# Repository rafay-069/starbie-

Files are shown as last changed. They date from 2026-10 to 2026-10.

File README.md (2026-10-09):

# Starbie: Yeti J.A.R.V.I.S. Edition

An expressive desktop companion robot and PC voice automation assistant housed inside a custom 3D-printed Yeti figurine, designed for the **Hack Club Half-Life** hardware initiative[cite: 5, 7].






---

## 3D Render & Board Preview

| 3D Carrier Board & Clearance | 2D Routed Copper Layout (0 DRC Errors) |
| :---: | :---: |
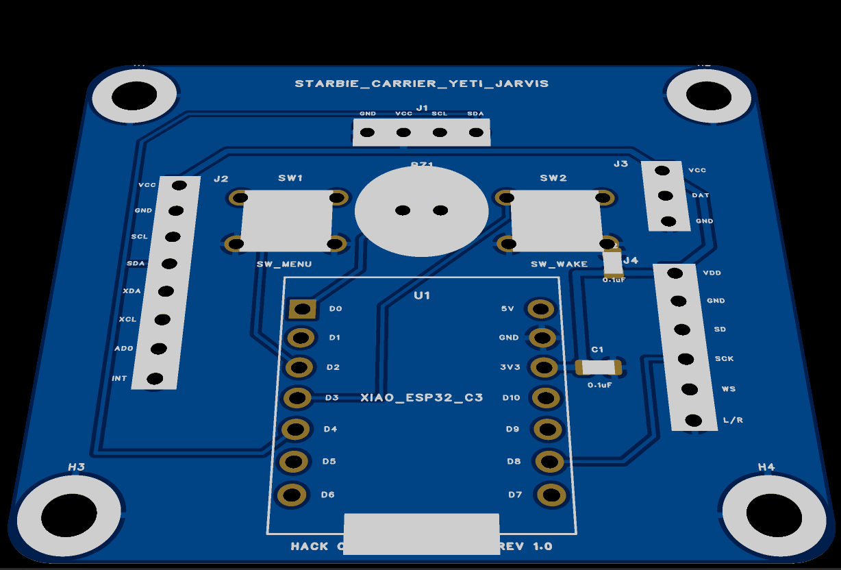
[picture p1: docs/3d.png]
Starbie PCB 3D Render
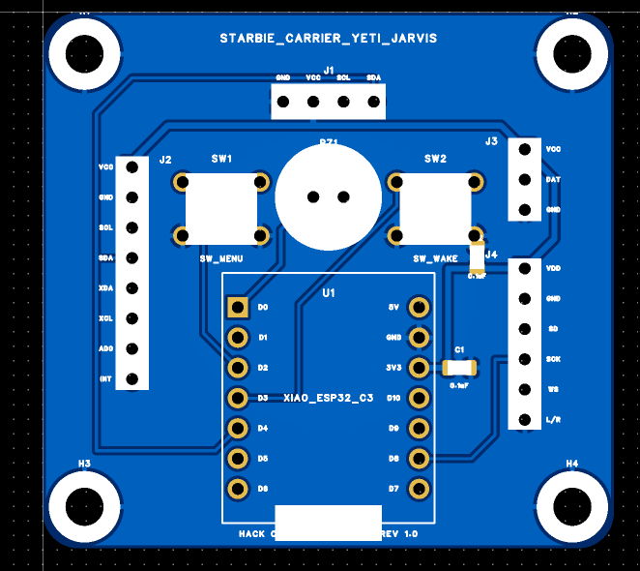
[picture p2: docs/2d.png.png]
Starbie PCB 2D Layout
|  |  |

---

## 1. System Architecture

Starbie uses a hybrid architecture: a local **Seeed Studio XIAO ESP32-C3** handles real-time sensor polling, I2S digital audio sampling, and high-framerate OLED facial rendering, while streaming telemetry and voice intents over USB-C to the host computer for Whisper speech recognition and LLM inference.

flowchart TD
    subgraph Power ["Power Distribution (+3V3 / GND)"]
        USB["USB-C 5V Input"] --> U1["Seeed Studio XIAO ESP32-C3"]
        U1 -->|Regulated 3.3V Rail| BUS3V["+3V3 Power Bus (0.50 mm)"]
        BUS3V --> C1["0.1 µF Decoupling C1"]
        BUS3V --> J1["0.96-inch SSD1306 OLED"]
        BUS3V --> J2["GY-521 MPU-6050 IMU"]
        BUS3V --> J3["DHT11 Climate Sensor"]
        BUS3V --> C2["0.1 µF Decoupling C2"]
        BUS3V --> J4["INMP441 I2S MEMS Mic"]
    end

    subgraph I2C ["Shared Fast I2C Bus"]
        U1 -- "D4 (GPIO6) / SDA" --> J1
        U1 -- "D5 (GPIO7) / SCL" --> J1
        J1 -.-> J2
    end

    subgraph I2S ["Digital Audio Capture (I2S)"]
        U1 -- "D8 (GPIO8) / SCK" --> J4
        U1 -- "D9 (GPIO9) / WS" --> J4
        U1 -- "D10 (GPIO10) / SD" <-- J4
    end

    subgraph IO ["Physical Input & Environment Telemetry"]
        U1 -- "D0 (GPIO2) / PWM" --> BZ1["Piezo Buzzer (Audio Chimes)"]
        U1 -- "D1 (GPIO3) / 1-Wire" <--> J3
        U1 -- "D2 (GPIO4) / Input" <-- SW1["Button 1 (Menu / Mode)"]
        U1 -- "D3 (GPIO5) / Input" <-- SW2["Button 2 (Action / Wake)"]
    end

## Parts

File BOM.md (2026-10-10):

# Starbie – bill of materials

<!-- Generated by Half Life from project cmuv6zgk30e7w01smhzuvei96. Edits here are overwritten on the next sync. -->
<!-- Generated: 2026-10-10T11:02:59.472Z -->

> [!NOTE]
> This parts list is mirrored from [Half Life](https://halflife.hackclub.com). Editing it here will not change the platform's copy, and the next sync overwrites this file.

| Week | Tier | Parts funding |
| --- | --- | --- |
| Week 1 | Tier 1 | $30.00 |

| Part | What it's for | Qty | Unit | Total | Vendor |
| --- | --- | --- | --- | --- | --- |
| [Seeed Studio XIAO ESP32-C3](https://robu.in) | Main microcontroller running logic and WiFi/BLE | 1 | $6.80 | $6.80 | [Robu.in](https://robu.in) |
| [0.96" I2C 128x64 OLED Display (SSD1306)](https://robu.in) | screen for pet | 1 | $2.00 | $2.00 | [Robu.in](https://robu.in) |
| [GY-521 MPU-6050 6-DOF Motion Sensor](https://robu.in) | for motion detection | 1 | $1.60 | $1.60 | [Robu.in](https://robu.in) |
| [DHT11 Temp & Humidity Sensor Module (3-pin)](https://robu.in) | for humidity and temp detection | 1 | $1.00 | $1.00 | [Robu.in](https://robu.in) |
| [Passive Buzzer Module (3.3V/5V)](https://robu.in) | PWM audio output for chirps and alerts | 1 | $0.50 | $0.50 | [Robu.in](https://robu.in) |
| [6x6x5mm Tactile Push Buttons (5-pack](https://robu.in) | for feed and menu action | 1 | $0.30 | $0.30 | [Robu.in](https://robu.in) |
| [40-Pin 2.54mm Female Header Strip](https://robu.in) | Socketing the XIAO to prevent soldering damage | 1 | $0.50 | $0.50 | [Robu.in](https://robu.in) |
| [830-Point Solderless Breadboard (MB-102)](https://robu.in) | for testing | 1 | $1.60 | $1.60 | [Robu.in](https://robu.in) |
| [Male-to-Male Breadboard Jumper Wires (65 pcs)](https://robu.in) | connections | 1 | $1.00 | $1.00 | [Robu.in](https://robu.in) |
| [INMP441 MEMS Omnidirectional I2S Microphone](https://robu.in) | Studio-grade digital voice capture for Whisper & AI | 1 | $1.80 | $1.80 | [robu](https://robu.in) |
| [3.7V 500mAh 1S LiPo Battery (PCM Protected)](https://robu.in) | Backup power when disconnected from laptop USB | 1 | $3.50 | $3.50 | [robu](https://robu.in) |
| [0805 SMD 0.1 µF (100 nF) Ceramic Capacitors (10-pack)](https://robu.in) | Rail decoupling filters for MCU & mic (C1, C2) | 1 | $0.20 | $0.20 | [robu](https://robu.in) |
| [1×40 Pin 2.54 mm Male Breakaway Header Strip](https://robu.in) | Breakaway male pins for sensor modules to plug in | 1 | $0.15 | $0.15 | [robu](https://robu.in) |
| [M3 Brass Hex Threaded Standoffs & Screws Kit](https://robu.in) | Fastening carrier board inside Yeti body mounting holes | 1 | $2.50 | $2.50 | [robu](https://robu.in) |
| [Multitec 07 Precision Wire Nipper / Flush Cutter](https://robu.in) | Trimming component pins flat on PCB bottom | 1 | $0.45 | $0.45 | [robu](https://robu.in) |
| [Anti-Static Curved Tweezers ESD-15](https://robu.in) | Placing tiny 0805 SMD capacitors while soldering | 1 | $0.45 | $0.45 | [robu](https://robu.in) |
| [Noel 25W Soldering Iron](https://robu.in) | Soldering headers, buzzer, and passives to board | 1 | $1.20 | $1.20 | [robu](https://robu.in) |
| [0.5 mm 50g Rosin Core Solder Wire](https://robu.in) | solder wire | 1 | $1.75 | $1.75 | [robu](https://robu.in) |
| **Parts subtotal** | — | — | — | **$27.30** | — |
| **Tax & shipping** | — | — | — | **$2.70** | — |
| **Total** | — | — | — | **$30.00** | — |

$0.00 left of the tier's funding.

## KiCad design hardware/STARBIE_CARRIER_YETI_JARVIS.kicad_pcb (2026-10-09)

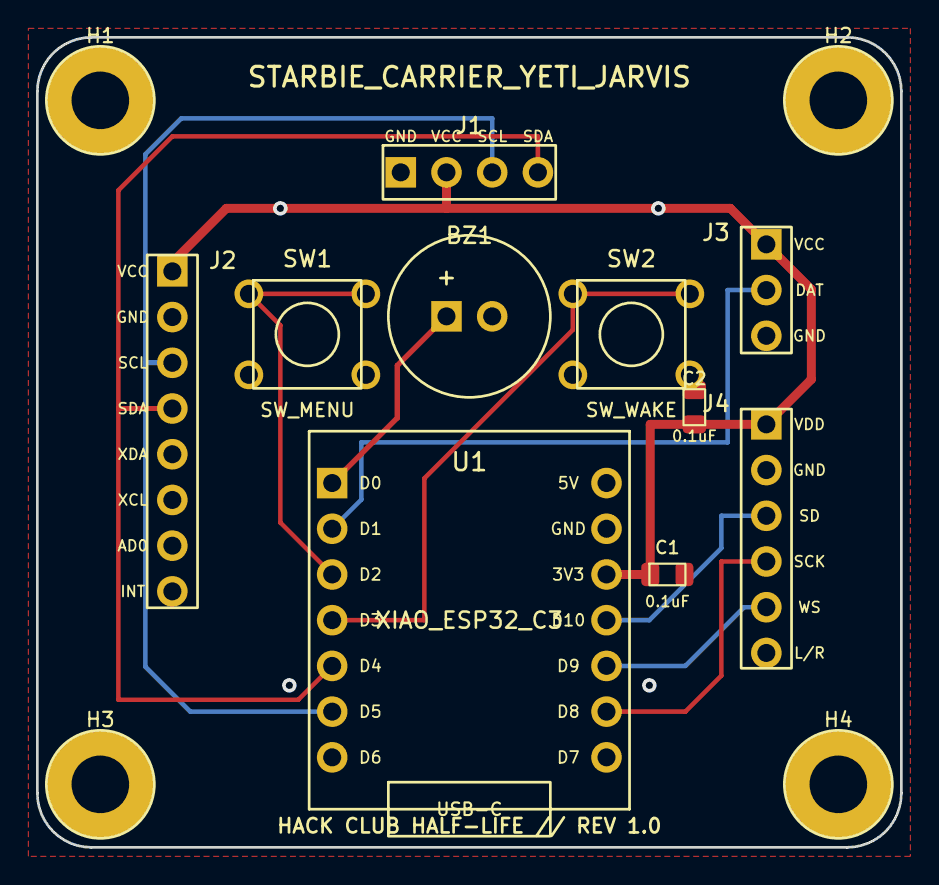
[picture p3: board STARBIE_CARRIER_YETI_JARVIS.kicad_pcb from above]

Board: 2 copper layers, 48.0 x 45.0 mm, 14 parts (0 on the bottom side), 11 nets.

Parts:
BZ1: Buzzer; Buzzer_12x9.5RM7.6
C1, C2: 0.1uF; C_0805_2012Metric
H1, H2, H3, H4: MountingHole_M3; MountingHole_3.2mm_M3_Pad_Via
J1: OLED_SSD1306; PinHeader_1x04_P2.54mm_Horizontal
J2: GY-521_MPU6050; PinHeader_1x08_P2.54mm_Vertical
J3: DHT11; PinHeader_1x03_P2.54mm_Vertical
J4: INMP441_MIC; PinHeader_1x06_P2.54mm_Vertical
SW1: SW_MENU; SW_PUSH_6mm
SW2: SW_WAKE; SW_PUSH_6mm
U1: XIAO_ESP32_C3; Seeed_XIAO_DIP14

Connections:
+3V3: C1.1, C2.1, J1.2, J2.1, J3.1, J4.1, U1.12
BTN_1: SW1.1, SW1.2, U1.3
BTN_2: SW2.1, SW2.2, U1.4
BUZZER: BZ1.1, U1.1
DHT_DATA: J3.2, U1.2
GND: BZ1.2, C1.2, C2.2, H1.1, H2.1, H3.1, H4.1, J1.1, J2.2, J2.7, J3.3, J4.2, J4.6, SW1.3, SW1.4, SW2.3, SW2.4, U1.13
I2C_SCL: J1.3, J2.3, U1.6
I2C_SDA: J1.4, J2.4, U1.5
I2S_SCK: J4.4, U1.9
I2S_SD: J4.3, U1.11
I2S_WS: J4.5, U1.10

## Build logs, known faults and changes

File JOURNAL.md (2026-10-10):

# Starbie – devlog

<!-- Generated by Half Life from project cmuv6zgk30e7w01smhzuvei96. Edits here are overwritten on the next sync. -->
<!-- Generated: 2026-10-10T16:19:15.174Z -->

> [!NOTE]
> This devlog is mirrored from [Half Life](https://halflife.hackclub.com). Editing it here will not change the platform's copy, and the next sync overwrites this file.

> A tiny motion-controlled digital pet, basically a desktop Tamagotchi. Totally not a Starboy.

| Week | Tier | Hours logged | Entries |
| --- | --- | --- | --- |
| Week 1 | Tier 1 | 5h | 1 |

## Contents

1. [2026-10-10 – ](#2026-10-10-screenshot-2026-10-10-214710httpshalflifehackclub)

## Design

### 2026-10-10 – 

**5h**



Architected the core hardware platform for Starbie (Yeti J.A.R.V.I.S. Edition) around the Seeed Studio XIAO ESP32-C3 microcontroller. Mapped peripheral assignments to prevent GPIO bus contention: shared fast I2C bus on GPIO6 (SDA) and GPIO7 (SCL) for both the 0.96" SSD1306 OLED and GY-521 MPU-6050 6-DoF IMU; 3-wire digital audio I2S bus on GPIO8 (SCK), GPIO9 (WS), and GPIO10 (SD) for the INMP441 MEMS microphone; and dedicated GPIO lines for the passive buzzer, DHT11 climate sensor, and dual tactile buttons. Built and wired the complete multi-sheet schematic in EasyEDA Pro, adding 0.1 µF 0805 SMD ceramic decoupling capacitors on the 3.3V bus and microphone VDD rail to filter high-frequency switching noise.









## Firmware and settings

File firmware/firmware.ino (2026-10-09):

#include <Wire.h>
#include <Adafruit_GFX.h>
#include <Adafruit_SSD1306.h>

// Starbie ESP32-C3 Pin Definitions
#define PIN_BUZZER    2   // D0
#define PIN_DHT       3   // D1
#define PIN_BTN_MENU  4   // D2
#define PIN_BTN_WAKE  5   // D3
#define PIN_I2C_SDA   6   // D4
#define PIN_I2C_SCL   7   // D5
#define PIN_I2S_SCK   8   // D8
#define PIN_I2S_WS    9   // D9
#define PIN_I2S_SD    10  // D10

#define SCREEN_WIDTH 128
#define SCREEN_HEIGHT 64
Adafruit_SSD1306 display(SCREEN_WIDTH, SCREEN_HEIGHT, &Wire, -1);

void setup() {
  Serial.begin(115200);
  pinMode(PIN_BTN_MENU, INPUT_PULLUP);
  pinMode(PIN_BTN_WAKE, INPUT_PULLUP);
  pinMode(PIN_BUZZER, OUTPUT);

  Wire.begin(PIN_I2C_SDA, PIN_I2C_SCL);
  if (display.begin(SSD1306_SWITCHCAPVCC, 0x3C)) {
    display.clearDisplay();
    display.setTextColor(SSD1306_WHITE);
    display.setTextSize(1);
    display.setCursor(16, 28);
    display.println("STARBIE ONLINE");
    display.display();
  }

  // Startup chime
  tone(PIN_BUZZER, 1046, 100);
  delay(120);
  tone(PIN_BUZZER, 2093, 150);
}

void loop() {
  if (digitalRead(PIN_BTN_MENU) == LOW) {
    tone(PIN_BUZZER, 880, 50);
    delay(150);
  }
  if (digitalRead(PIN_BTN_WAKE) == LOW) {
    tone(PIN_BUZZER, 1760, 50);
    delay(150);
  }
  delay(10);
}

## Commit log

2026-10-09 Add files via upload
    Complete Week 1: Add PCB design, Gerbers, and 3D renders
    [STARBIE_CARRIER_YETI_JARVIS.kicad_pcb, STARBIE_CARRIER_YETI_JARVIS.kicad_sch]
2026-10-09 Remove power distribution diagram from README
    Removed mermaid diagram for power distribution from README.
2026-10-09 starter firmware for Week 1,
    Initialize the display and setup button inputs.
2026-10-19 Add Bill of Materials section to README
    Added a Bill of Materials (BOM) section with components and specifications.
2026-10-31 Revise BOM with detailed descriptions and pricing
    Updated the Bill of Materials (BOM) section with detailed descriptions, unit prices, and vendor links for components.
